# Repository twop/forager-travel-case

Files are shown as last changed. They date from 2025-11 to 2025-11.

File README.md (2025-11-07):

# Overview
Travel case for an amazing keyboard [Forager](https://github.com/carrefinho/forager) designed by [carrefinho](https://github.com/carrefinho).

Primarily designed by my friend [Jacob](https://github.com/freakerepo) for me <3 with my humble input and original sketches.

## Features
- 4 parts designed to be 3D printed without support
- Magnetic latch, uses 24 10mm×3mm round magnets (press fit but can be glued)
- Integrated storage for the original tenting legs
- Case covers serve dual purpose as wrist rests
- Compact, but should have enough space for taller keycaps like [Lame](https://github.com/braindefender/KLP-Lame-Keycaps/)
- Simple: no glue or screws required

## Pictures

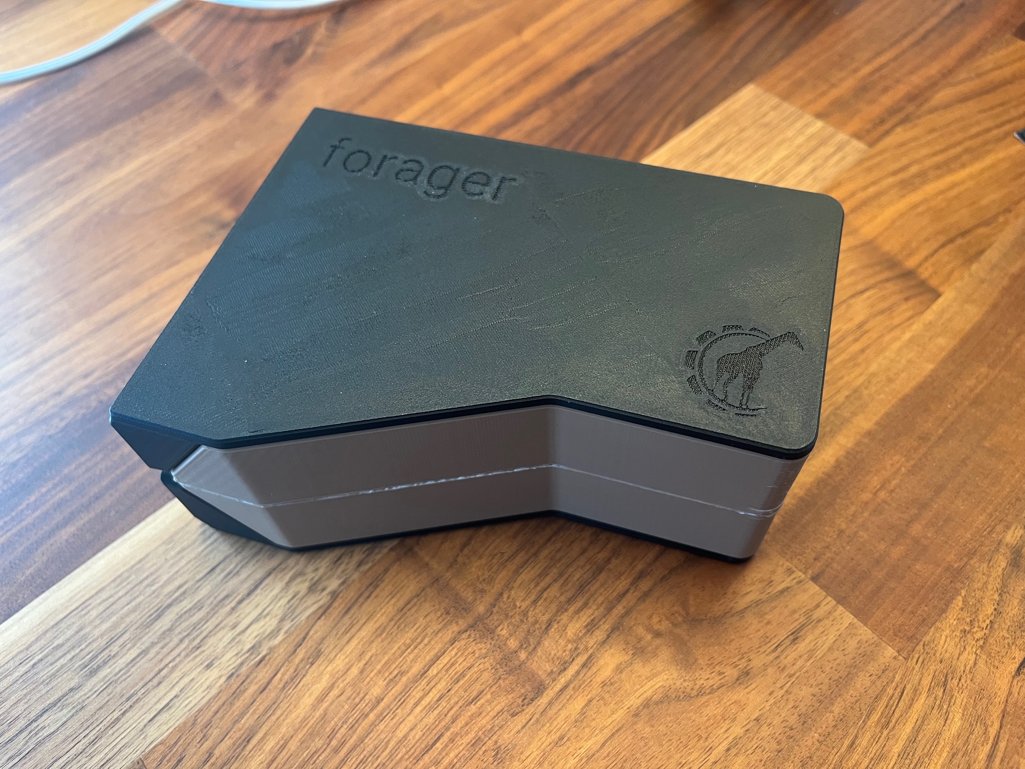
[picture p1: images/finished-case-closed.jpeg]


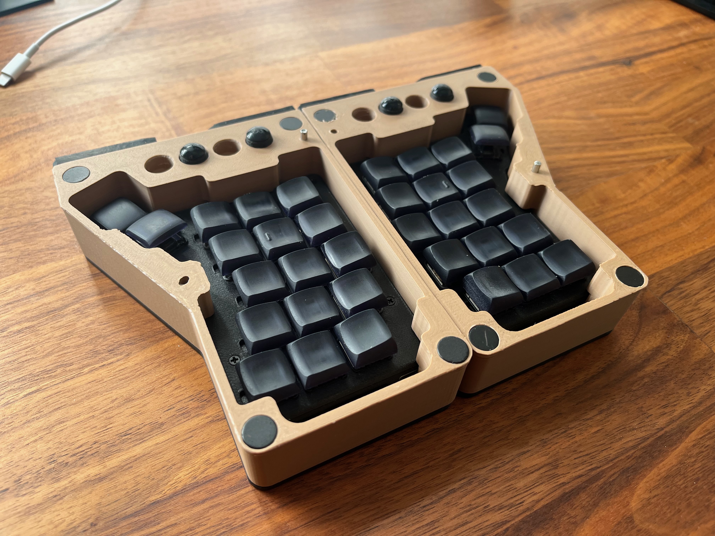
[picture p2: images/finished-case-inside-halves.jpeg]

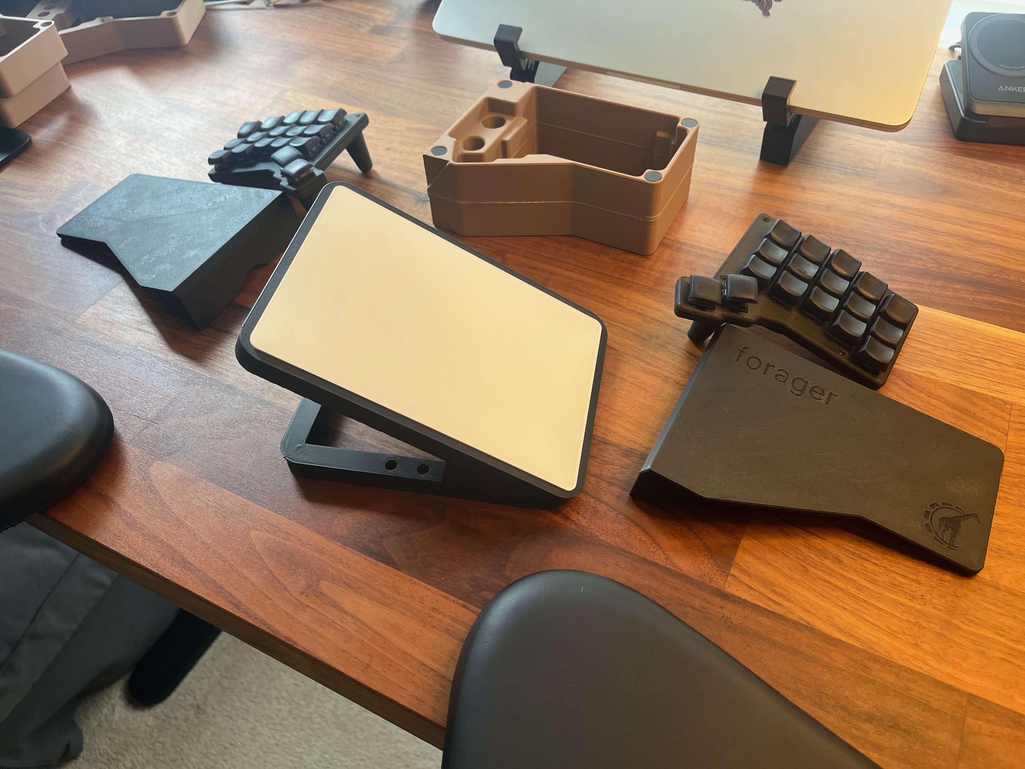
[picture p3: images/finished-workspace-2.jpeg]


More [here](/images)

## Bill of Materials
I'm going to use Amazon links, but these should be widely accessible. And some can be reused from the Forager build.

- 24× neodymium magnets: 10mm diameter × 3mm thick. [Amazon](https://www.amazon.com/dp/B0C7C7GG9W) 
- 4× 10mm diameter 3mm thick hemisphere rubber pads from the Forager build guide, something like [that](https://www.amazon.com/dp/B07G8926LH) 
- [Grip sticker](https://www.amazon.com/dp/B0CTT75B19)
- 2× 8mm×3mm rods from the Forager build guide, [Amazon](https://www.amazon.com/dp/B07M9TT4P2)

## Links
 - [Build guide](BUILD.md)
- .STEP and .STL files located [here](/model-files)
- [Onshape project](https://cad.onshape.com/documents/e2c91bed5374849b3c122744/w/bbca4005ae6c906ce5c7ceb8/e/0b8fca7d9af09da5f9981931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)

## Thanks
- To my friend [Jacob](https://www.linkedin.com/in/jacob-freake-24748863/) for partnering on designing the case. You are the best (though, as always).
- To [carrefinho](https://github.com/carrefinho), your work saved my wrist.

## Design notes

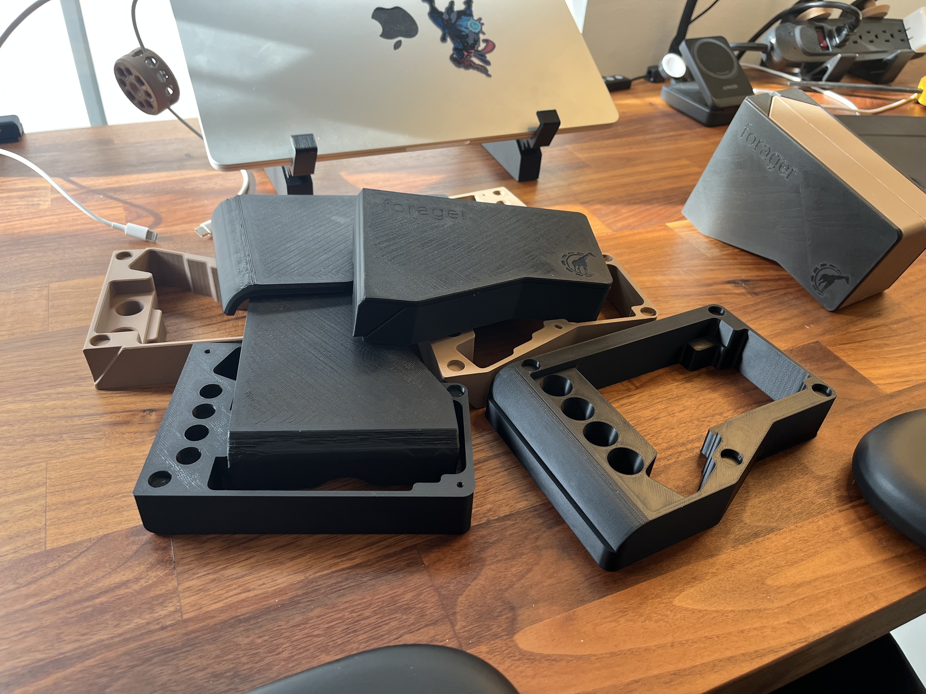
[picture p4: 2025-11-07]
images/mistakes-were-made.jpg

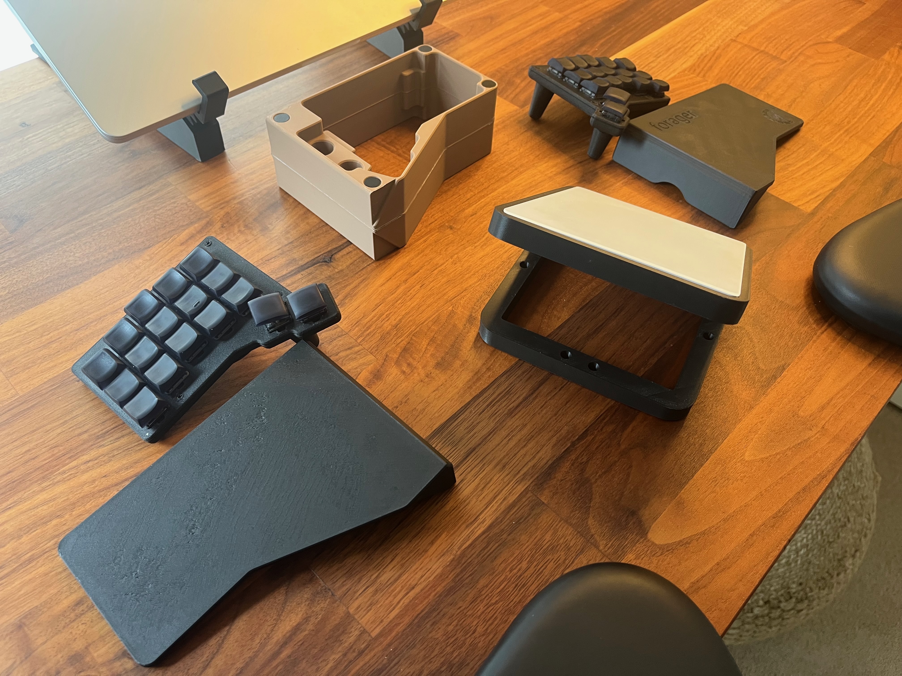
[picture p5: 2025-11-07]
images/finished-workspace-1.jpeg

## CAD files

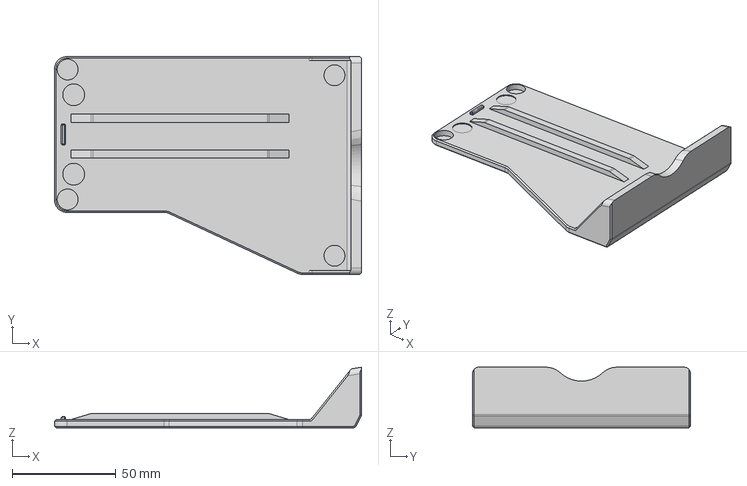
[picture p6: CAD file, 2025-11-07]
model-files/Upper Cover.step
147.9 x 105.0 x 29.2 mm

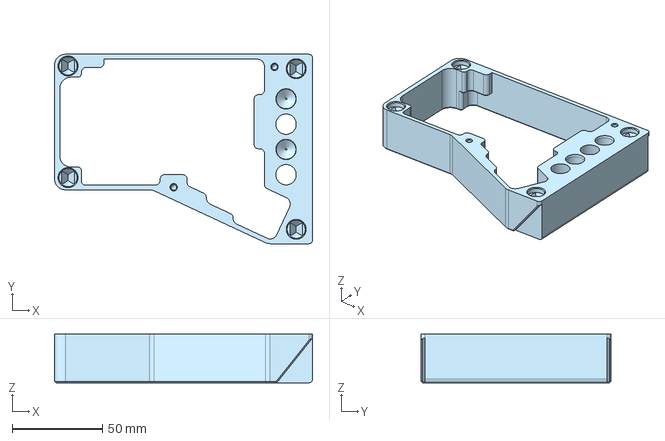
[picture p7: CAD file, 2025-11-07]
model-files/Upper Case Body.step
142.9 x 105.0 x 26.9 mm

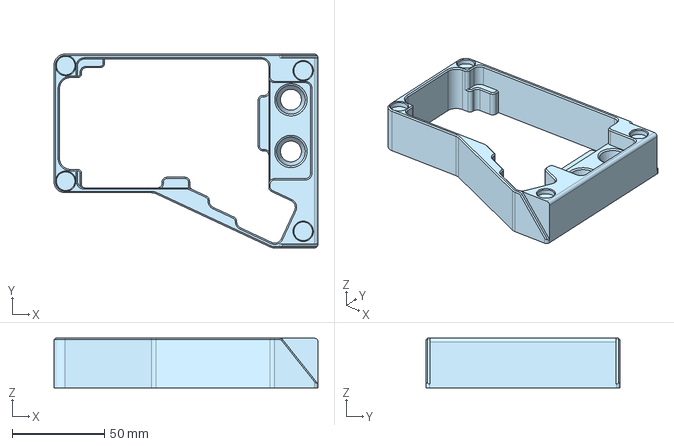
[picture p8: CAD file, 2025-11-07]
model-files/Lower Case Body.step
142.9 x 105.0 x 26.9 mm

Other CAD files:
model-files/Lower Cover.step
model-files/Lower Case Body.stl
model-files/Lower Cover.stl
model-files/Upper Case Body.stl
model-files/Upper Cover.stl

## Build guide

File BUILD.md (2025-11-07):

## 3D Print Everything
Files located in [model-files](/model-files). 

- Note that some might need to be flipped upside down in orientation for printing. The model files are taken from the assembly view, hence the assembly orientation.
- All 4 files should be printable without supports. Magnet holes have special geometry that don't require bridging nor support.
- I printed with 0.1 mm layer height for higher fidelity, but all the prototype prints I have done are 0.2 mm.

## Bill of Materials

See [README.md](README.md)

## Assembly

### Insert Magnets into the Case (Outer Side)
The spacing is designed for "press-fit", but you might want to add glue.

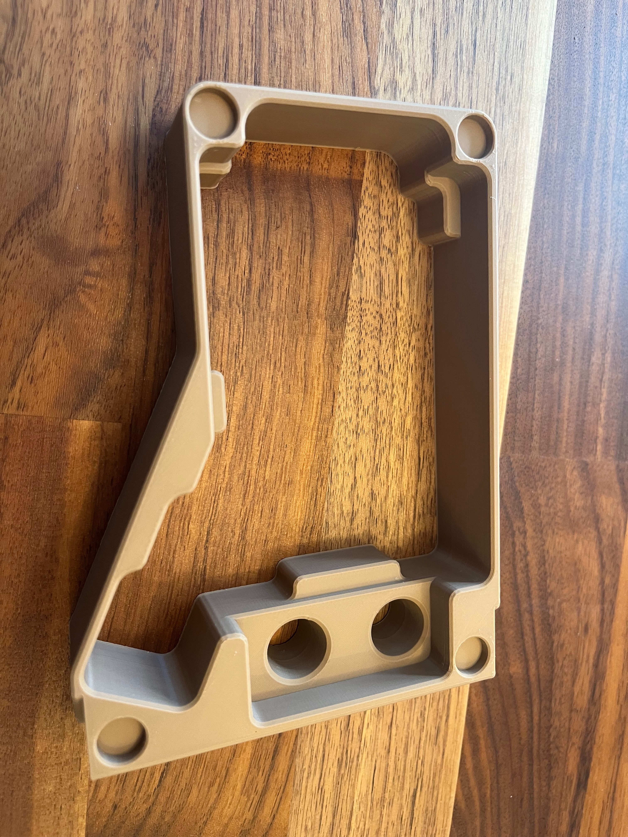
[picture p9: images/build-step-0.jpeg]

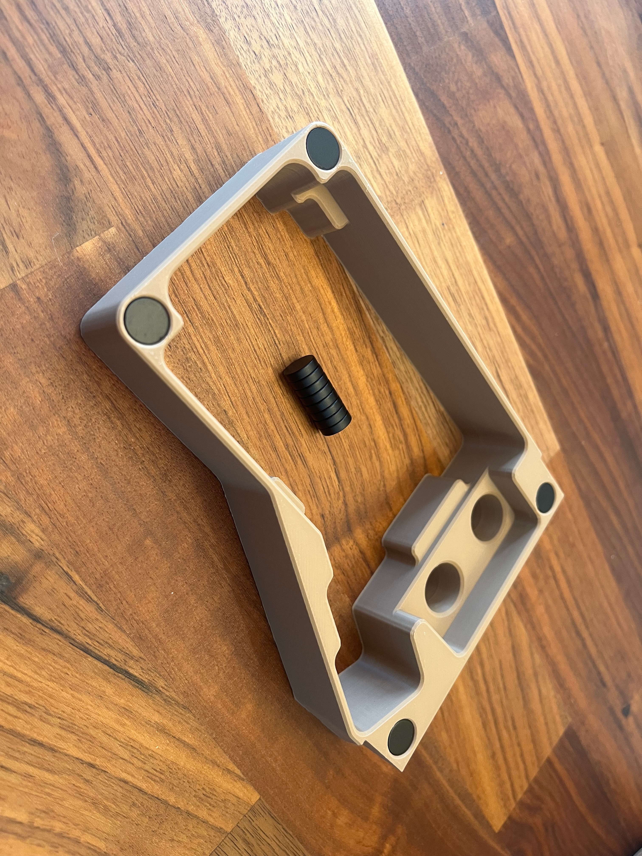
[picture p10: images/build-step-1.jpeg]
half-with-magnets


I suggest having magnets oriented in the same way.

Repeat for the second half.

### Insert Magnets into the Cover

Pay attention to the magnet orientation relative to the case

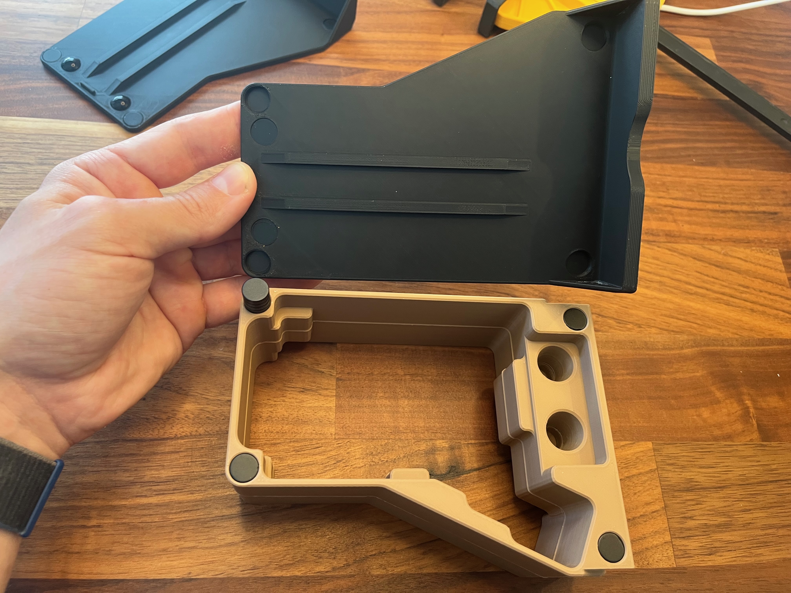
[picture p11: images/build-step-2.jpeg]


Repeat for the second half.

### Insert Magnets and Pins into the Case (Inner Side)
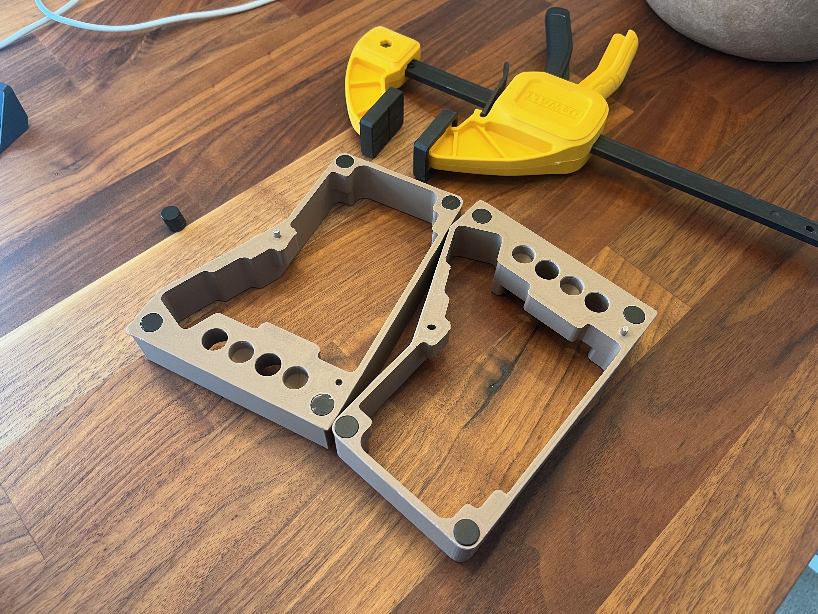
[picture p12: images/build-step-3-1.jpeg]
before-pins

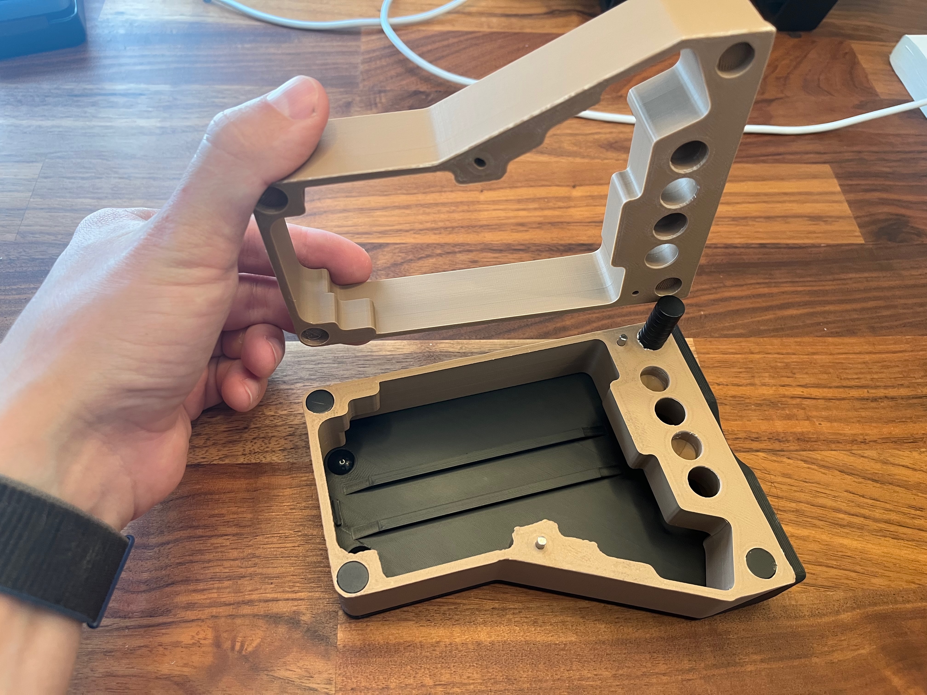
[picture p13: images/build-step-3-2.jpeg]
connecting-two-halves


- Pins are designed to be inserted into the half that has two round holes; it has tighter spacing.
- Note the magnet orientation, so both halves would actually connect!
- Because this is the side that was on the 3D printer bed, it may be a bit tight (depending on filament), so some instrument might be helpful to apply firm but gentle pressure.

### Rubber Stickers and Pads for Palm Rests
The cover has minor depressions of 10 mm in diameter to indicate where the stickers should go. The spacing is designed for pads at least 3.5 mm thick, so when the cover is angled, it still sits on the pads.
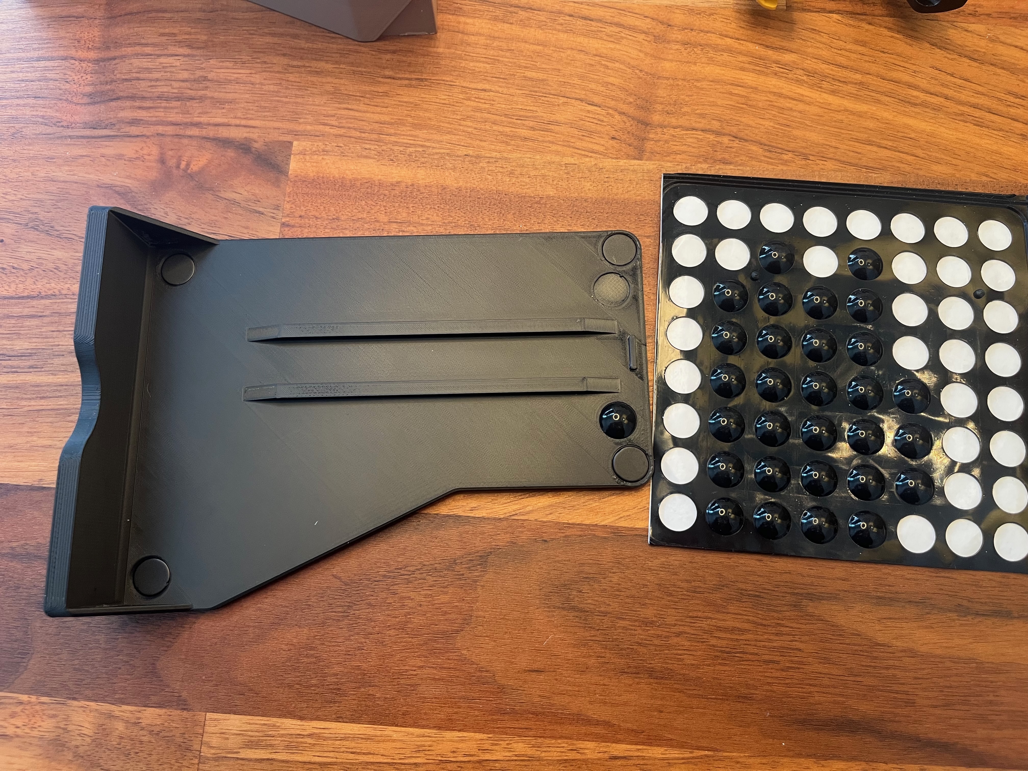
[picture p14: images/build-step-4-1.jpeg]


---

Next are rubber stickers that you need to cut out yourself. The design has about 5 mm spacing for friction stickers, so you have options. Although the solution in BoM worked out great for me.

Basically, you need 4 stripes that would provide friction when used as a palm rest. Note that the surface is angled to be flush with the table when standing.
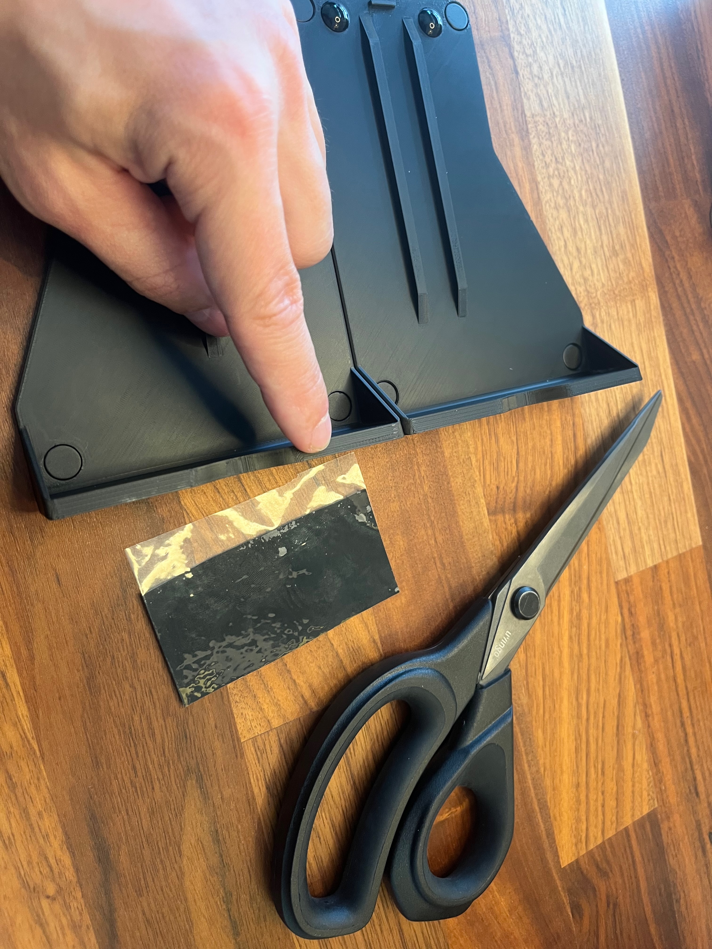
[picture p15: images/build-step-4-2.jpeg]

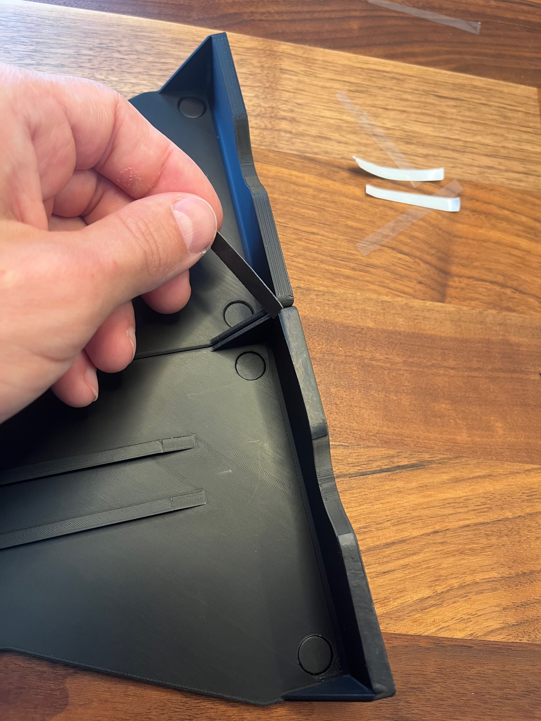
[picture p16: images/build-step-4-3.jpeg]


### Put It All Together

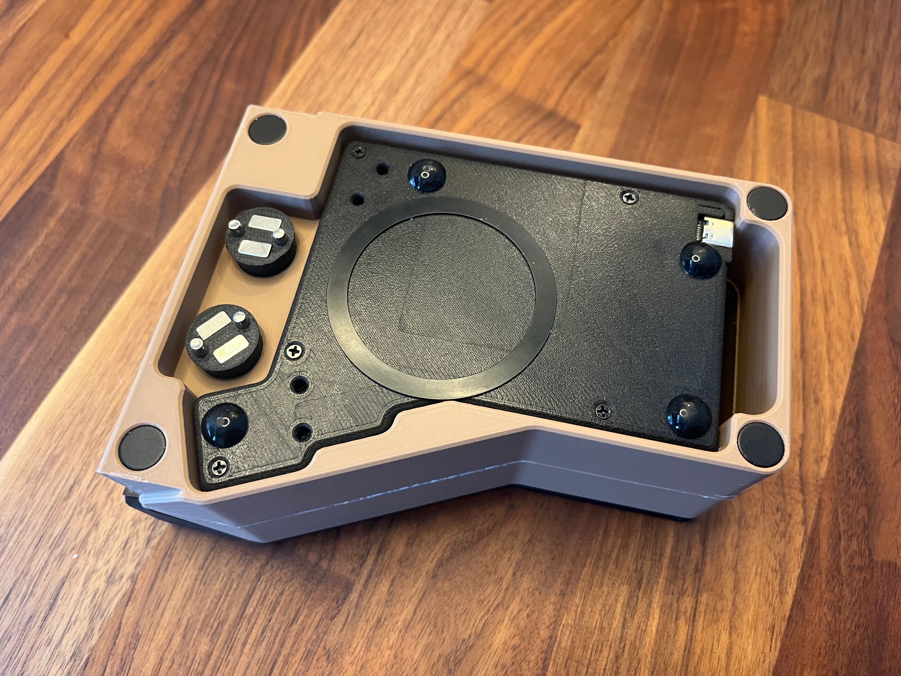
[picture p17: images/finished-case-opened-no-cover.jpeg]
opened-no-cover

finished-inside-halves

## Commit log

2025-11-07 added model files
    [Lower Case Body.step, Lower Case Body.stl, Lower Cover.step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]
2025-11-07 added images and renamed model files
    [Lower Case Body.stl, Lower Cover.stl, Upper Case Body Cover.stl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]
